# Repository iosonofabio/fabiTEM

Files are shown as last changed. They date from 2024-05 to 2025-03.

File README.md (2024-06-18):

<picture align="center">
  TOTEM logo
</picture>

fabiTEM is a 38 key, column-staggered, ortho-ergo, choc split keyboard forked from the [TOTEM](https://github.com/GEIGEIGEIST/TOTEM/tree/main). It is powered by:

 - an [RP2040](https://www.raspberrypi.com/documentation/microcontrollers/rp2040.html) (left side), and
 - an [MCP23017](https://www.microchip.com/en-us/product/mcp23017) IO expander (right side).

The core design concept is that everything was designed at the desk - zero hardware tinkering. Factory prints PCB and case, assembles the components, and all left for the user to do is put a few screws in. The jury is out as of whether that's gonna work in practice :-)

***

## LAYOUT

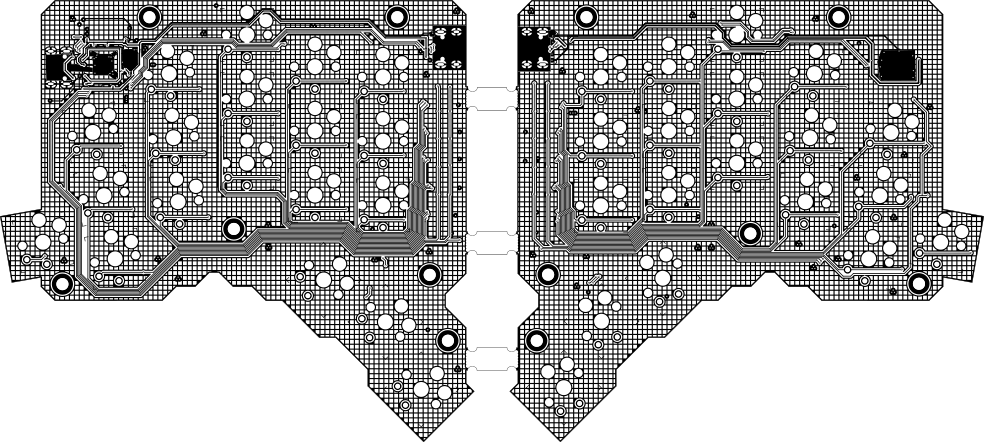
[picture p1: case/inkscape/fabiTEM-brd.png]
fabiTEM layout


***

## PCB

[Here](/PCB/) you can find the KiCad files for the fabiTEM.

***

## CASE

Being designed.

## CREDITS

### INSPIRATION

The original design with diodes on the front and two controllers is from [TOTEM](https://github.com/GEIGEIGEIST/TOTEM/tree/main). I've modified it quite a bit to add more angle on the thumb keys, simplify factory assembly (everything is on the back), forgo breakout boards for an actual RP2040, use a single MCU to simplify flashing, etc.

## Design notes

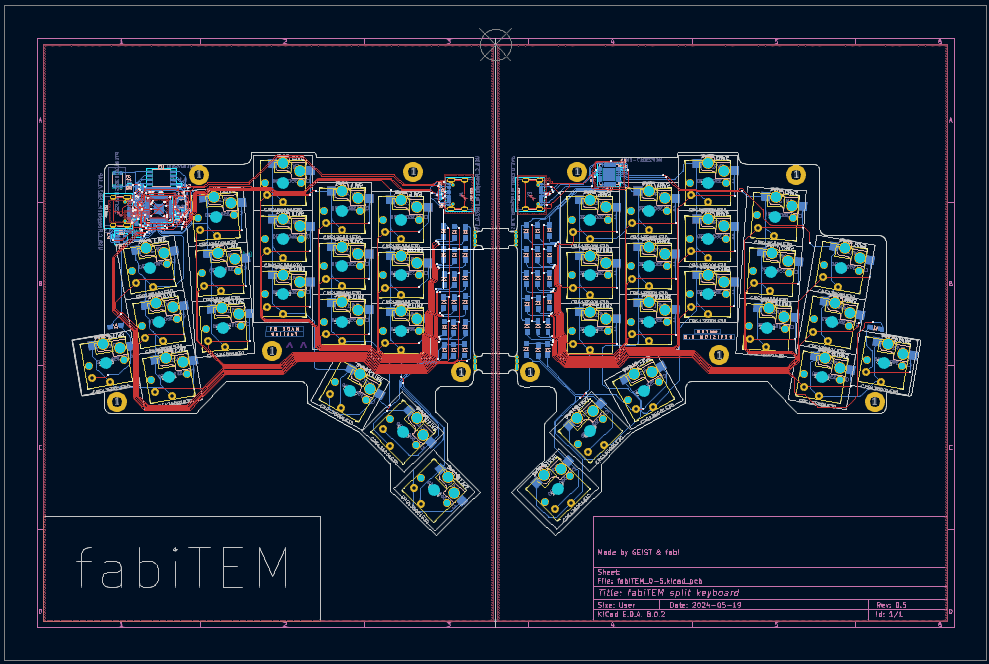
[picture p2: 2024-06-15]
docs/images/fabiTEM.png

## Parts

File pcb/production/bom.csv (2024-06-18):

Designator | Footprint | Quantity | Value | LCSC Part #
C1, C2 | 0201 | 2 | 15 pF
C10, C11, C12, C13, C14, C15, C16, C17, C7, C8, C9 | 0201 | 11 | 0.1 uF
C3, C4, C5, C6 | 0201 | 4 | 1 uF
D1 | DIOM3616X98N | 1 | MBR120VLSFT1G
DL1, DL10, DL11, DL12, DL13, DL14, DL15, DL16, DL17, DL18, DL19, DL2, DL3, DL4, DL5, DL6, DL7, DL8, DL9, DR1, DR10, DR11, DR12, DR13, DR14, DR15, DR16, DR17, DR18, DR19, DR2, DR3, DR4, DR5, DR6, DR7, DR8, DR9 | Diode_SOD123 | 38 | 1N4148W
J1, J2, J3 | USB_C_Receptacle_GCT_USB4105-xx-A_16P_TopMnt_Horizontal | 3 | USB_C_Receptacle_USB2.0_14P
R1, R11, R12, R13, R8 | 0201 | 5 | 1k
R10, R9 | 0201 | 2 | 5.1k
R2, R3, R6, R7 | 0201 | 4 | 10k
R4, R5 | 0201 | 2 | 27
S1 | PTS810SJG250SMTRLFS | 1 | PTS810SJK250SMTRLFS
SWL1, SWL10, SWL11, SWL12, SWL13, SWL14, SWL15, SWL16, SWL17, SWL18, SWL19, SWL2, SWL3, SWL4, SWL5, SWL6, SWL7, SWL8, SWL9, SWR1, SWR10, SWR11, SWR12, SWR13, SWR14, SWR15, SWR16, SWR17, SWR18, SWR19, SWR2, SWR3, SWR4, SWR5, SWR6, SWR7, SWR8, SWR9 | Kailh_socket_PG1350_reverse | 38 | CPG135001S30
U1 | SOT-23-5 | 1 | AP2112K-3.3
U2 | QFN-56-1EP_7x7mm_P0.4mm_EP3.2x3.2mm | 1 | RP2040
U3 | SOIC127P790X216-8N | 1 | W25Q16JVSSIQ
U5 | QFN65P600X600X100-29N | 1 | MCP23017-EML
Y1 | ABM8-272-T3 | 1 | ABM8-272-T3

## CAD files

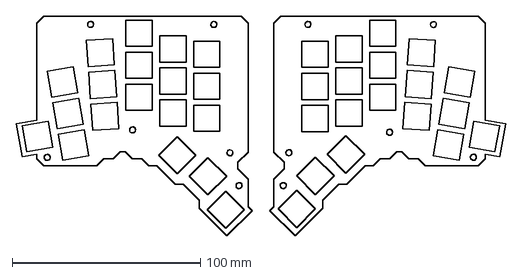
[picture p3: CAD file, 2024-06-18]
case/inkscape/fabiTEM-0.7-cutouts.dxf
260.3 x 117.0 mm

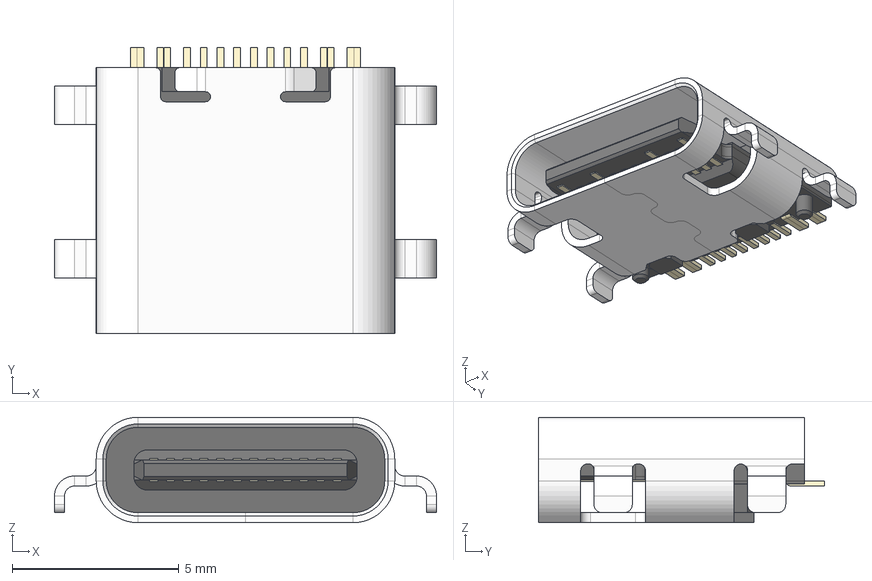
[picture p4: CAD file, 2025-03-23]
pcb/3D/HRO TYPE-C-31-M-14.step
11.5 x 8.56 x 3.16 mm
Shroud
Plastic Body & Connector

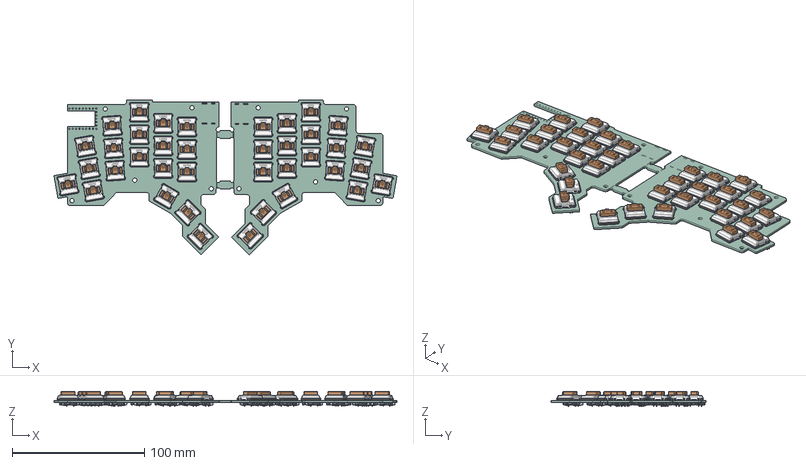
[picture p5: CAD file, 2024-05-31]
PCB/fabiTEM_edge_0_5.step
259.3 x 117.1 x 11.0 mm
(Unsaved) x 38
PG1350 x 38
fabiTEM_0-4_PCB

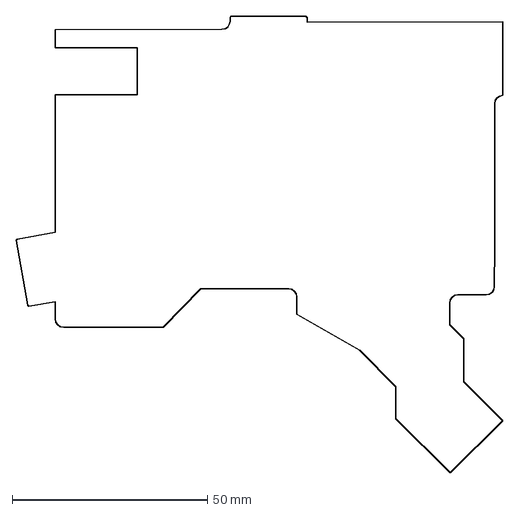
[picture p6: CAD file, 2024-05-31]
case/inkscape/fabiTEM_0-4-Edge_Cuts_left.dxf
124.7 x 117.0 mm

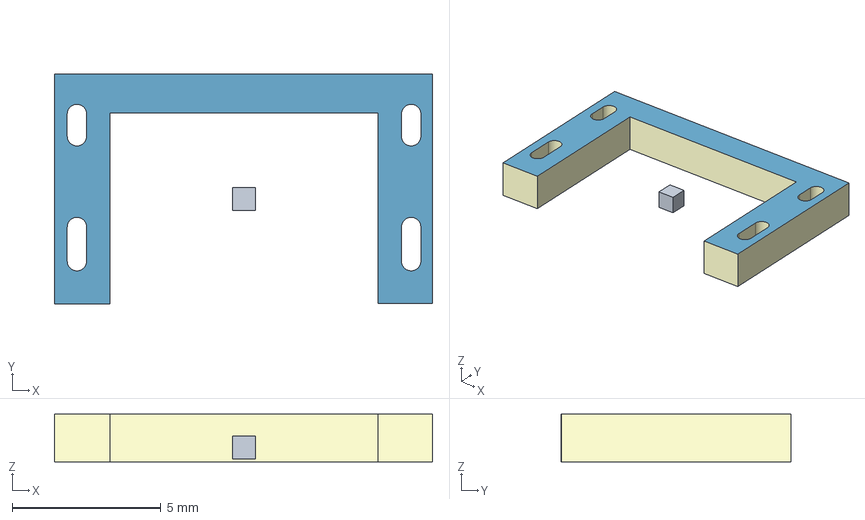
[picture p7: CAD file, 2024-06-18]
pcb/3D/DEALON-usb-type-c-16p-mid-mount.step
12.7 x 7.75 x 1.60 mm
Board
USB-SMD_TYPE-C16PCB1.6073

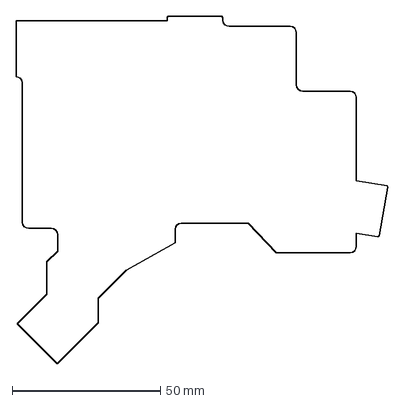
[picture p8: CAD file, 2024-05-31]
case/inkscape/fabiTEM_0-4-Edge_Cuts_right.dxf
125.4 x 117.1 mm

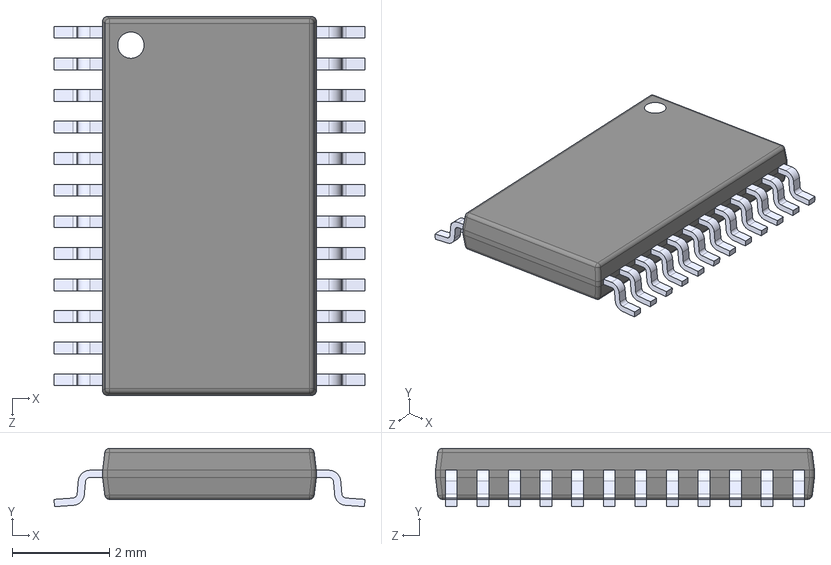
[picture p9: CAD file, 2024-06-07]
pcb/3D/TCA9555PWR.step
6.40 x 1.20 x 7.80 mm

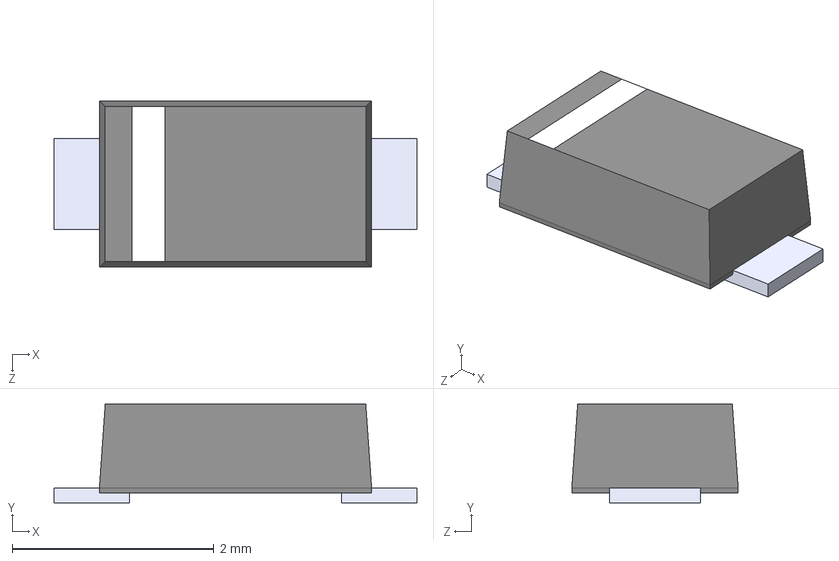
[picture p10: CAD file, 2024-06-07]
pcb/3D/MBR120VLSFT1G.step
3.60 x 0.98 x 1.65 mm

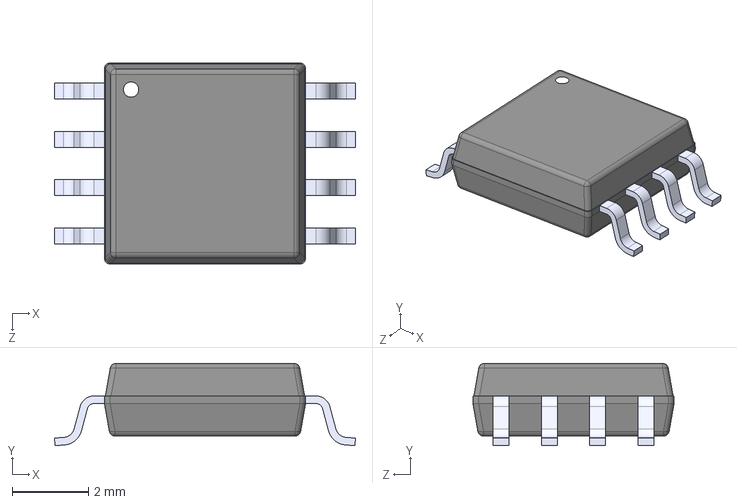
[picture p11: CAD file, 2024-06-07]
pcb/3D/W25Q16JVSSIQ.step
7.90 x 2.16 x 5.28 mm

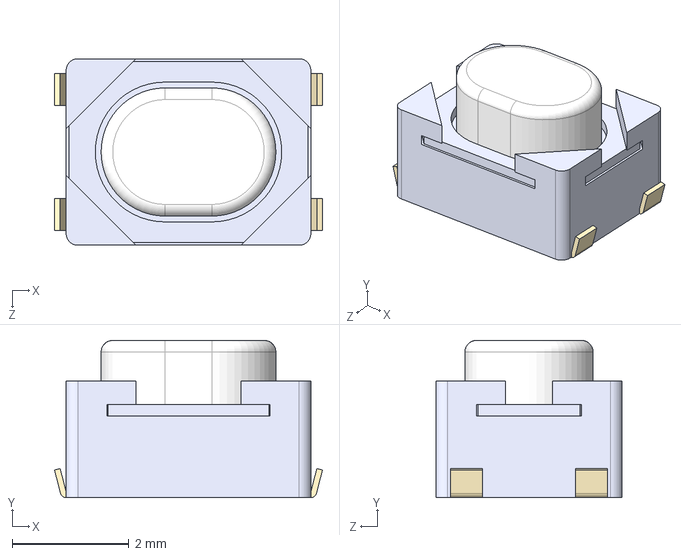
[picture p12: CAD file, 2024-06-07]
pcb/3D/PTS810SJK250SMTRLFS.step
4.60 x 2.70 x 3.20 mm

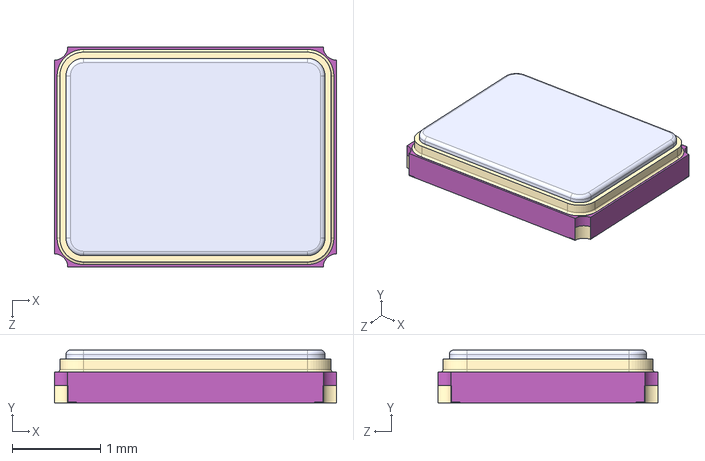
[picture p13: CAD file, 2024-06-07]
pcb/3D/NX3225SA-12MHZ-STD-CSR-6.STEP
3.20 x 0.6 x 2.50 mm

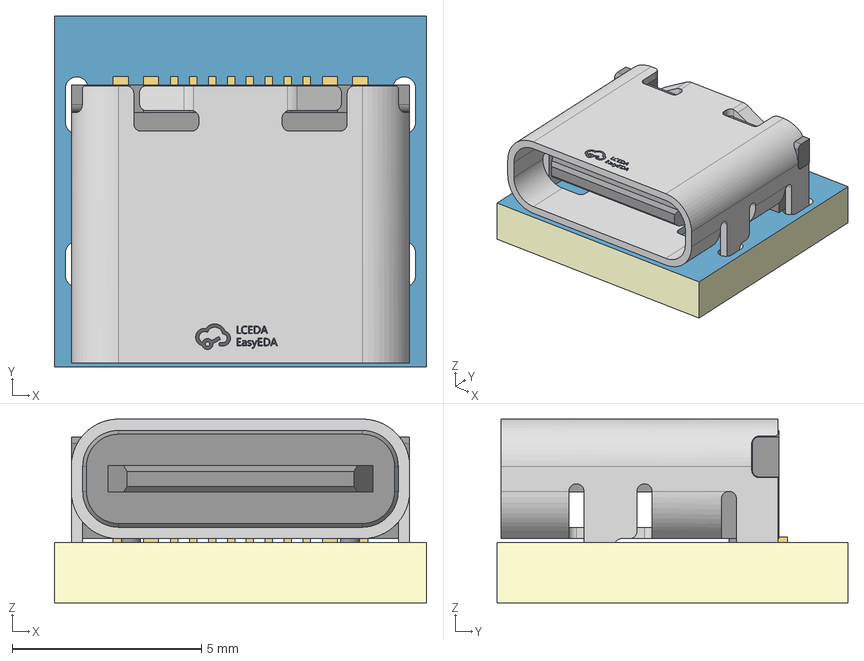
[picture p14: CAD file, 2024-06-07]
pcb/3D/TYPE-C 16PIN 2MD(073).step
9.83 x 9.27 x 4.86 mm
Board

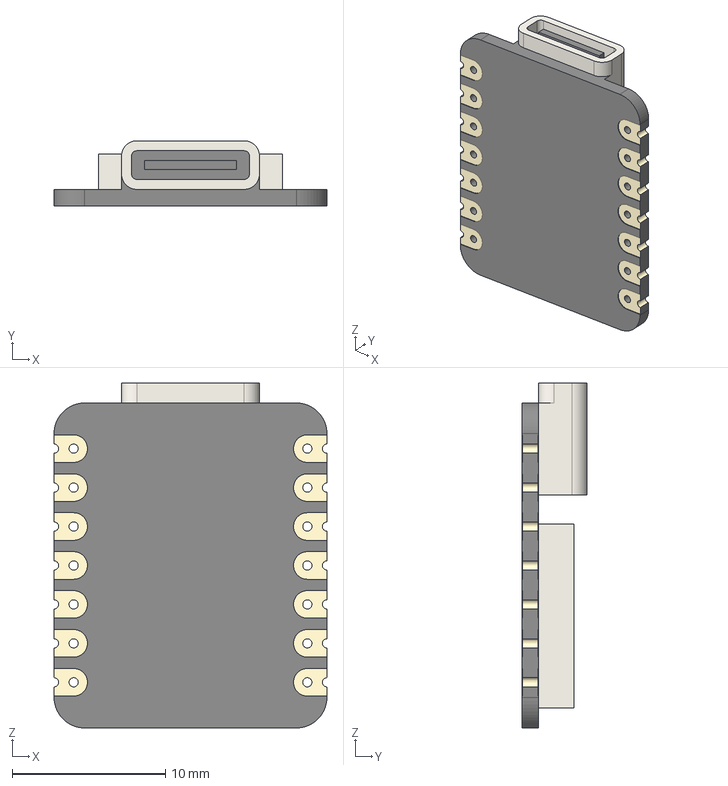
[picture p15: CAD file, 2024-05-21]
pcb/3D/xiao-ble-tht.step
17.8 x 4.27 x 22.5 mm

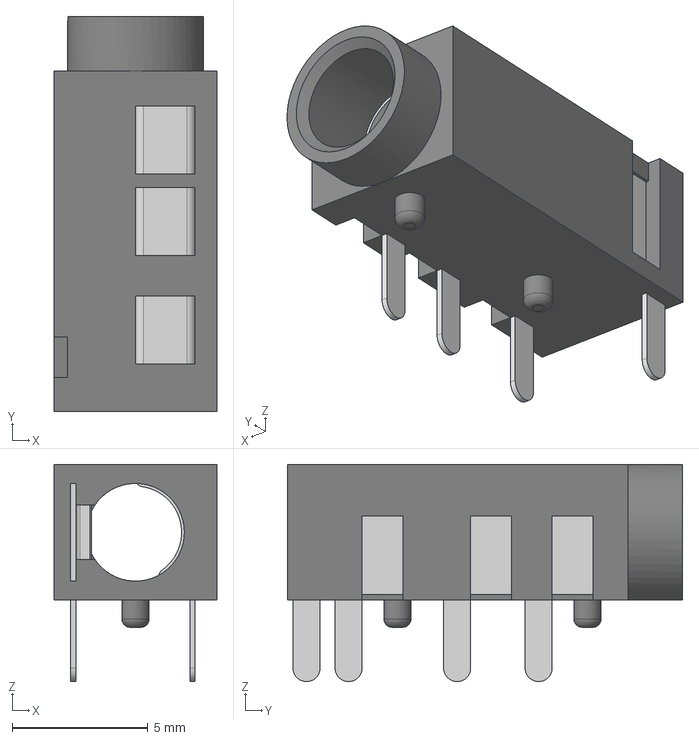
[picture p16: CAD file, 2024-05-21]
pcb/3D/PJ320A.STEP
6.00 x 14.6 x 8.00 mm

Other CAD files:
pcb/3D/SW_SKHLLC.step
pcb/3D/D_SOD-123.step
pcb/3D/Kailh_socket_PG1350_optional.STEP
pcb/3D/Kailh_switch_PG1350_optional.step
case/old/USB/step/TOTEMcase_v08_6mm_USB_Bottom_L.step
case/old/USB/step/TOTEMcase_v08_6mm_USB_Bottom_R.step
case/old/USB/step/TOTEMcase_v08_6mm_USB_Top_L.step
case/old/USB/step/TOTEMcase_v08_6mm_USB_Top_R.step
case/old/USB/stl/TOTEMcase_v08_6mm_USB_Bottom_L.stl
case/old/USB/stl/TOTEMcase_v08_6mm_USB_Bottom_R.stl
case/old/USB/stl/TOTEMcase_v08_6mm_USB_Top_L.stl
case/old/USB/stl/TOTEMcase_v08_6mm_USB_Top_R.stl
case/old/step/TOTEMcase_v08_6mm_Bottom_L.step
case/old/step/TOTEMcase_v08_6mm_Bottom_R.step
case/old/step/TOTEMcase_v08_6mm_Top_L.step
case/old/step/TOTEMcase_v08_6mm_Top_R.step
case/old/stl/TOTEMcase_v08_6mm_Bottom_L.stl
case/old/stl/TOTEMcase_v08_6mm_Bottom_R.stl
case/old/stl/TOTEMcase_v08_6mm_Top_L.stl
case/old/stl/TOTEMcase_v08_6mm_Top_R.stl
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

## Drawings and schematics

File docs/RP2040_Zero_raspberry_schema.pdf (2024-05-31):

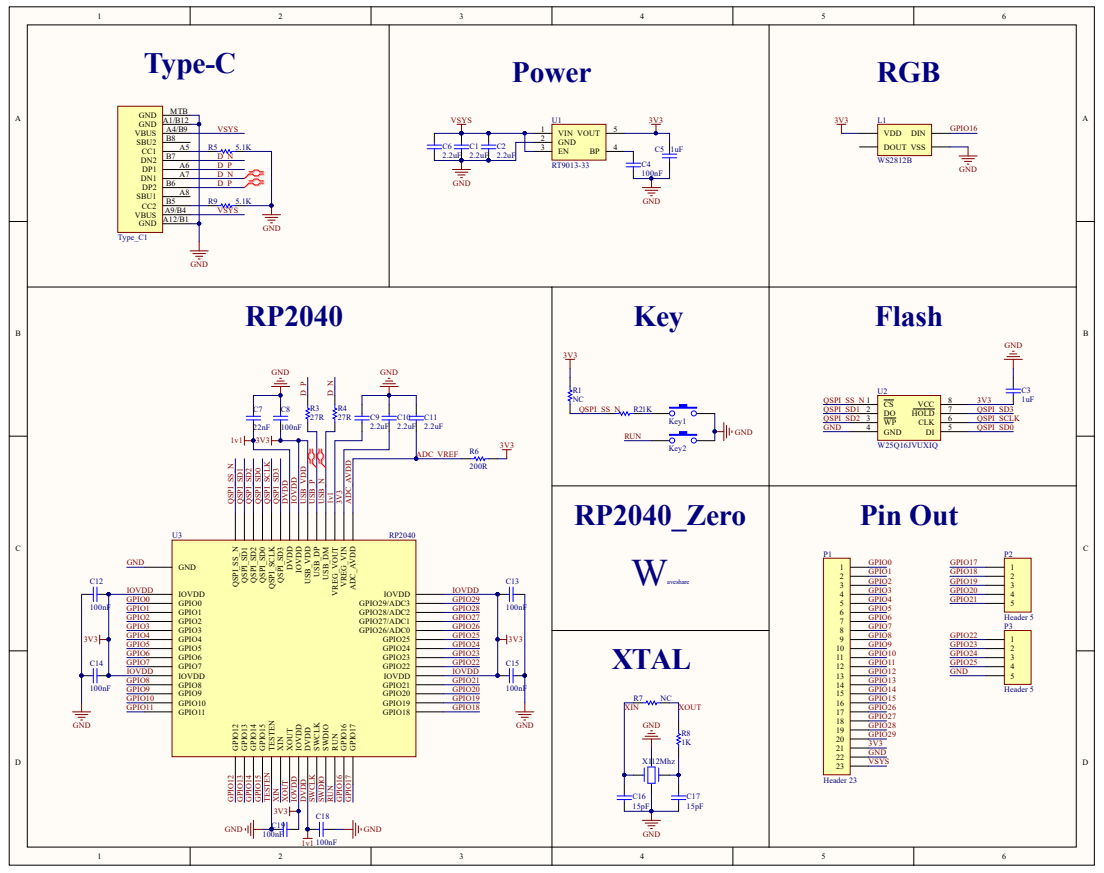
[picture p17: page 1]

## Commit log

2024-05-18 Convert to wired, before moving keys
    [totem_0_3.kicad_sch]
2024-05-18 Shape, wiring, some labels
2024-05-20 Fully wired
    [totem_0_3.kicad_sch]
2024-05-21 Rename project and move diodes to back
    [D_SOD-123.step, Kailh_socket_PG1350_optional.STEP, Kailh_switch_PG1350_optional.step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]
2024-05-31 3d case beginning, before own chip
    [D_SOD-123.step, Kailh_socket_PG1350_optional.STEP, Kailh_switch_PG1350_optional.step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]
2024-06-07 Rewiring of the entire thing, triple USB-C, IO expander
    [10118192-0001LF.step, 1054500101.step, D_SOD-123.step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]
2024-06-15 adafruit io expander
    [MCP23017-EML.step, fabiTEM_0-5.kicad_sch]
2024-06-18 version 0.7, new shape, top mounted usb
    [10118192-0001LF.step, 1054500101.step, DEALON-usb-type-c-16p-mid-mount.step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]
